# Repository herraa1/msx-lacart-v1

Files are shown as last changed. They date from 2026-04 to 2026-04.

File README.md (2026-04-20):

# MSX LOGICAL ANALYZER CART

This is a MSX cartridge to facilitate the use of a Logical Analyzer with MSX cartridges and slot signals.

It uses [Agustín Gimenez Bernad](https://github.com/gusmanb) Raspberry Pico 2 based [logicanalizer](https://github.com/gusmanb/logicanalyzer) as a companion card.

## Current Status

* First prototype PCB sent for manufacturing as of Apr 3rd 2026.
* First prototype PCB tested successfully as of Apr 18th 2026.

> [!NOTE]
> Documentation in progress

## [Hardware](hardware/kicad/)

The msx-lacart is made of a 4-layer PCB with minimal components.

### [msx-lacart-v1-build1](hardware/kicad/msx-lacart-v1-build1/)

:white_check_mark: This board has been successfully built and tested.

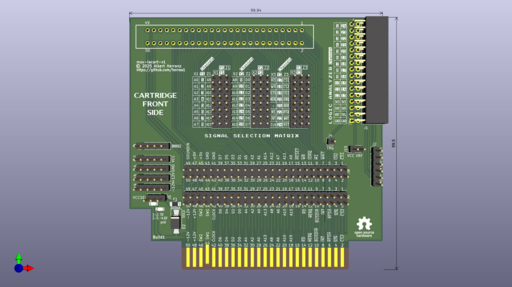
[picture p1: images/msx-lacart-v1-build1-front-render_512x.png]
[](images/msx-lacart-v1-build1-front-render.png)

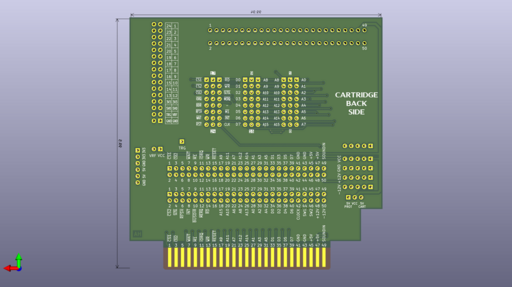
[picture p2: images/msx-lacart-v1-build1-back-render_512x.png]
[](images/msx-lacart-v1-build1-back-render.png)

[Bill Of Materials (BoM)](https://htmlpreview.github.io/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)

[Schematic and PCB](https://kicanvas.org/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)

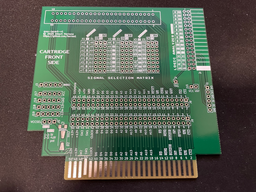
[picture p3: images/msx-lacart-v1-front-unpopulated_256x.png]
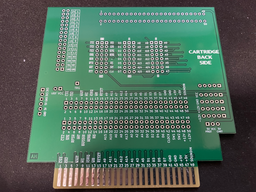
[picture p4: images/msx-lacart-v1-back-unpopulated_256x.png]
|[](images/msx-lacart-v1-front-unpopulated-9145.png)|[](images/msx-lacart-v1-back-unpopulated-9146.png)|
|-|-|
|msx-lacart-v1 build1<br>PCB unpopulated front|msx-lacart-v1 build1<br>PCB unpopulated back|

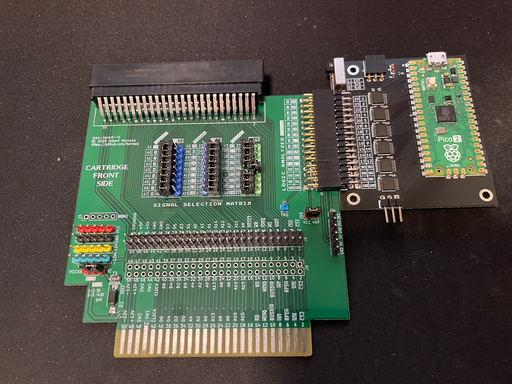
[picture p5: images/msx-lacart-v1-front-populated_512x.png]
|[](images/msx-lacart-v1-front-populated-9143.png)|
|:--|
|msx-lacart-v1 build1 PCB populated front|

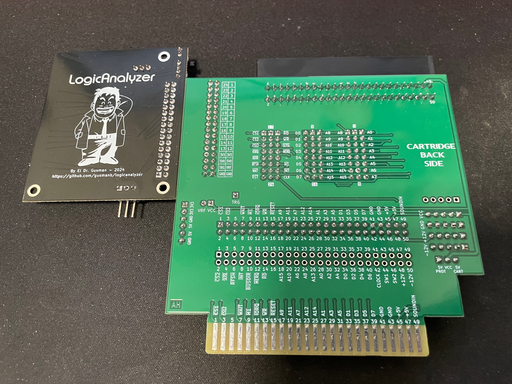
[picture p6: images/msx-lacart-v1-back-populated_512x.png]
|[](images/msx-lacart-v1-back-populated-9144.png)|
|:--|
|msx-lacart-v1 build1 PCB populated back|

## Usage

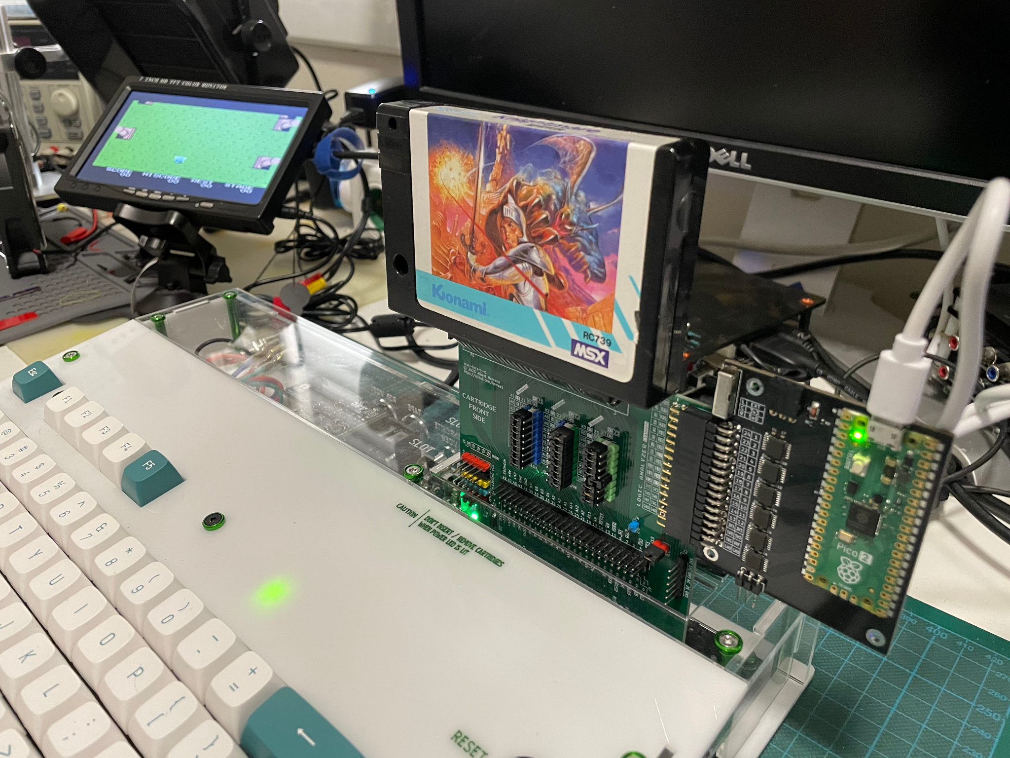
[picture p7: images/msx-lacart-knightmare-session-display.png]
|[](images/msx-lacart-knightmare-session-display.png)|
|:--|
|msx-lacart-v1 inserted into slot1 of a MSX JFF inspecting a Knighmare cartridge|

|[](images/msx-lacart-knightmare-session-analyzer.png)|
|:--|
|msx-lacart-v1 with Logic Analyzer capture session|

```
                    di                                      ;[0000] f3
                    jp        $02d7                         ;[0001] c3 d7 02
[...]
                    ld        a,$82                         ;[02d7] 3e 82
                    out       ($ab),a                       ;[02d9] d3 ab
                    xor       a                             ;[02db] af
                    out       ($a8),a                       ;[02dc] d3 a8
                    ld        a,$50                         ;[02de] 3e 50
                    out       ($aa),a                       ;[02e0] d3 aa
                    ld        de,$ffff                      ;[02e2] 11 ff ff
                    xor       a                             ;[02e5] af
                    ld        c,a                           ;[02e6] 4f
                    out       ($a8),a                       ;[02e7] d3 a8
                    sla       c                             ;[02e9] cb 21
                    ld        b,$00                         ;[02eb] 06 00
                    ld        hl,$ffff                      ;[02ed] 21 ff ff
                    ld        (hl),$f0                      ;[02f0] 36 f0
                    ld        a,(hl)                        ;[02f2] 7e
                    sub       $0f                           ;[02f3] d6 0f
                    jr        nz,$0302                      ;[02f5] 20 0b
[...]
                    ld        hl,$bf00                      ;[0302] 21 00 bf
                    ld        a,(hl)                        ;[0305] 7e
                    cpl                                     ;[0306] 2f
                    ld        (hl),a                        ;[0307] 77
```
||
|:--|
|Original MSX BIOS Z80 instructions from BIOS disassembly|

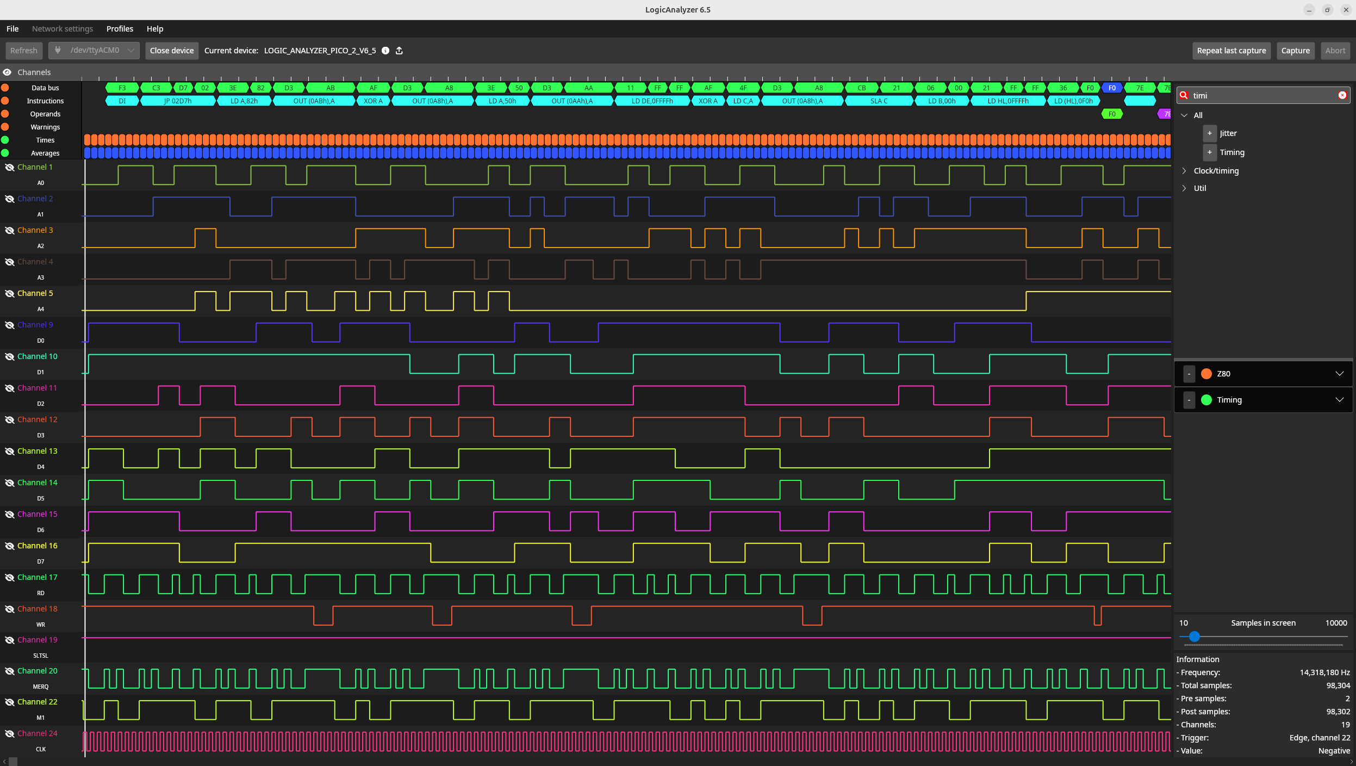
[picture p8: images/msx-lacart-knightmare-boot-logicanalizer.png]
|[](images/msx-lacart-knightmare-boot-logicanalizer.png)|
|:--|
|El Dr Gusman Logic Analyzer 6.5 showing MSX BIOS Z80 boot instructions captured using msx-lacart-v1|

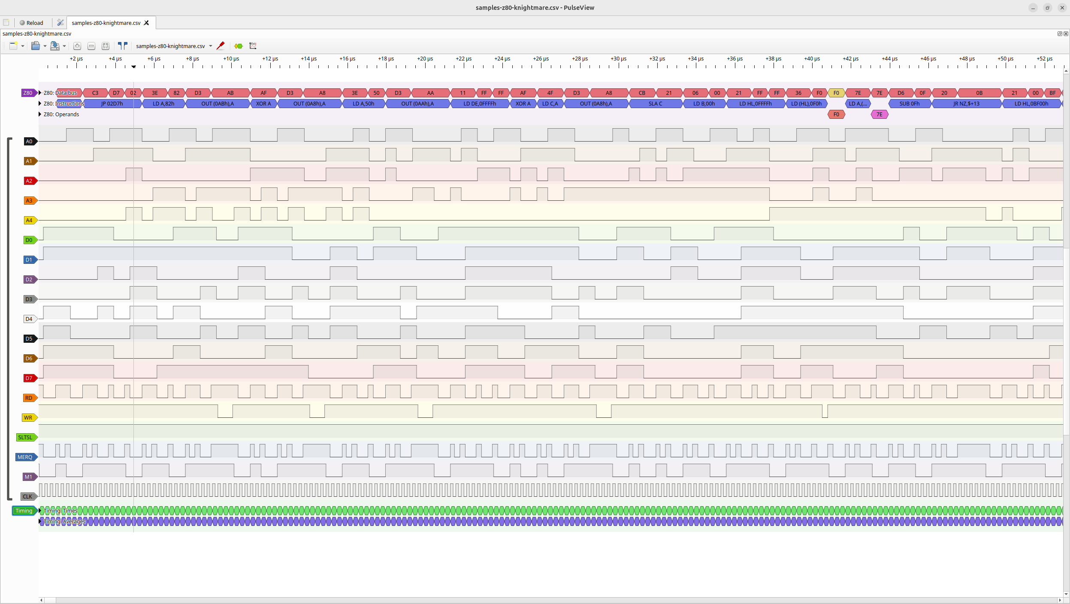
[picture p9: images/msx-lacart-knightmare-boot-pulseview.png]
|[](images/msx-lacart-knightmare-boot-pulseview.png)|
|:--|
|PulseView loaded with CSV export of MSX BIOS Z80 boot instructions captured using msx-lacart-v1|

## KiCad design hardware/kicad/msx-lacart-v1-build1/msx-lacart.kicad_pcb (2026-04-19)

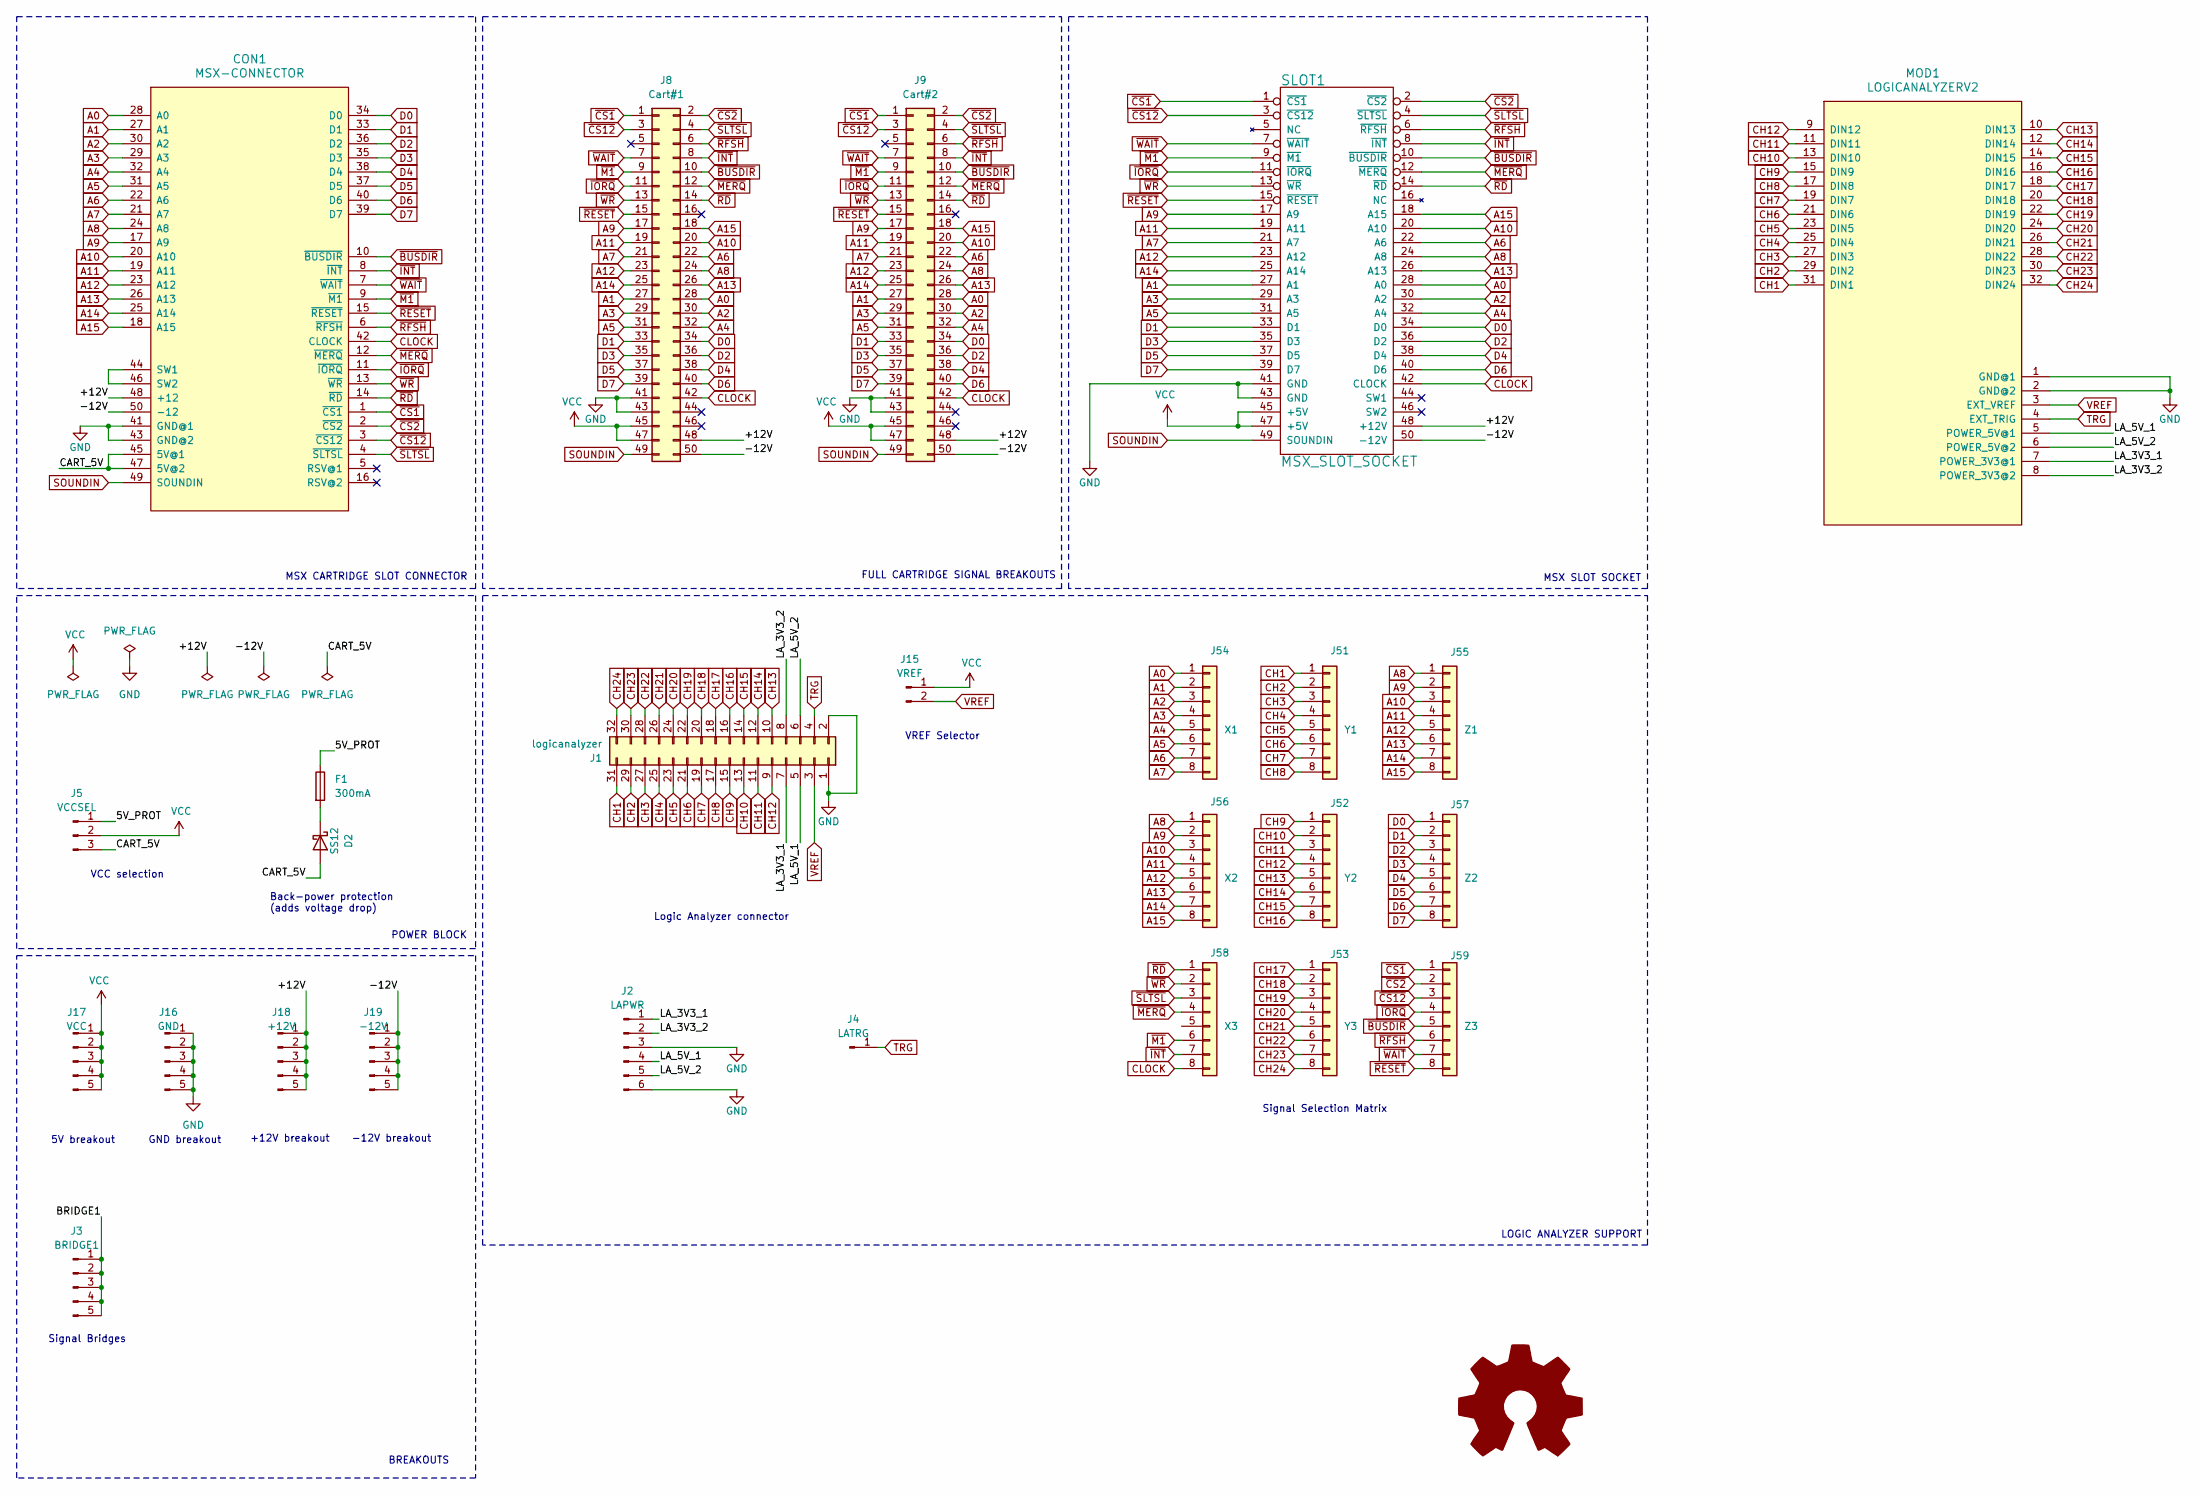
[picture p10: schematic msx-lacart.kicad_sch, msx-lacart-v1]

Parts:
CON1: MSX-CONNECTOR; CARTRIDGE_MSX_NOCUT
D2: SS12; D_SMA-SMB_Universal_Handsoldering
F1: 300mA; Fuse_1206_3216Metric_Pad1.42x1.75mm_HandSolder
J1: logicanalyzer; PinSocket_2x16_P2.54mm_Horizontal
J2: LAPWR; PinHeader_1x06_P2.54mm_Vertical
J3: BRIDGE1; PinHeader_1x05_P2.54mm_Vertical
J4: LATRG; PinHeader_1x01_P2.54mm_Vertical
J5: VCCSEL; PinHeader_1x03_P2.54mm_Vertical
J8: Cart#1; PinHeader_2x25_P2.54mm_Vertical
J9: Cart#2; PinHeader_2x25_P2.54mm_Vertical
J15: VREF; PinHeader_1x02_P2.54mm_Vertical
J16: GND; PinHeader_1x05_P2.54mm_Vertical
J17: VCC; PinHeader_1x05_P2.54mm_Vertical
J18: +12V; PinHeader_1x05_P2.54mm_Vertical
J19: -12V; PinHeader_1x05_P2.54mm_Vertical
J51: Y1; PinHeaderCustom_1x08_P2.54mm_Vertical
J52: Y2; PinHeaderCustom_1x08_P2.54mm_Vertical
J53: Y3; PinHeaderCustom_1x08_P2.54mm_Vertical
J54: X1; PinHeaderCustom_1x08_P2.54mm_Vertical
J55: Z1; PinHeaderCustom_1x08_P2.54mm_Vertical
J56: X2; PinHeaderCustom_1x08_P2.54mm_Vertical
J57: Z2; PinHeaderCustom_1x08_P2.54mm_Vertical
J58: X3; PinHeaderCustom_1x08_P2.54mm_Vertical
J59: Z3; PinHeaderCustom_1x08_P2.54mm_Vertical
MOD1: LOGICANALYZERV2; LogicAnalyzerV2
SLOT1: MSX_SLOT_SOCKET; Conn_Edge_50P
SYM1: Logo_Open_Hardware_Large; OSHW-Logo_7.5x8mm_SilkScreen

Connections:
/5V_PROT: F1.1, J5.1
/+12V: CON1.48 (+12), J8.48, J9.48, J18.1, J18.2, J18.3, J18.4, J18.5, SLOT1.48 (+12V)
/-12V: CON1.50 (-12), J8.50, J9.50, J19.1, J19.2, J19.3, J19.4, J19.5, SLOT1.50 (-12V)
/BRIDGE1: J3.1, J3.2, J3.3, J3.4, J3.5
/CART_5V: CON1.45 (5V@1), CON1.47 (5V@2), D2.2 (A), J5.3
/LA_3V3_1: J1.7, J2.1, MOD1.7 (POWER_3V3@1)
/LA_3V3_2: J1.8, J2.2, MOD1.8 (POWER_3V3@2)
/LA_5V_1: J1.5, J2.4, MOD1.5 (POWER_5V@1)
/LA_5V_2: J1.6, J2.5, MOD1.6 (POWER_5V@2)
A0: CON1.28 (A0), J8.28, J9.28, J54.1, SLOT1.28 (A0)
A1: CON1.27 (A1), J8.27, J9.27, J54.2, SLOT1.27 (A1)
A2: CON1.30 (A2), J8.30, J9.30, J54.3, SLOT1.30 (A2)
A3: CON1.29 (A3), J8.29, J9.29, J54.4, SLOT1.29 (A3)
A4: CON1.32 (A4), J8.32, J9.32, J54.5, SLOT1.32 (A4)
A5: CON1.31 (A5), J8.31, J9.31, J54.6, SLOT1.31 (A5)
A6: CON1.22 (A6), J8.22, J9.22, J54.7, SLOT1.22 (A6)
A7: CON1.21 (A7), J8.21, J9.21, J54.8, SLOT1.21 (A7)
A8: CON1.24 (A8), J8.24, J9.24, J55.1, J56.1, SLOT1.24 (A8)
A9: CON1.17 (A9), J8.17, J9.17, J55.2, J56.2, SLOT1.17 (A9)
A10: CON1.20 (A10), J8.20, J9.20, J55.3, J56.3, SLOT1.20 (A10)
A11: CON1.19 (A11), J8.19, J9.19, J55.4, J56.4, SLOT1.19 (A11)
A12: CON1.23 (A12), J8.23, J9.23, J55.5, J56.5, SLOT1.23 (A12)
A13: CON1.26 (A13), J8.26, J9.26, J55.6, J56.6, SLOT1.26 (A13)
A14: CON1.25 (A14), J8.25, J9.25, J55.7, J56.7, SLOT1.25 (A14)
A15: CON1.18 (A15), J8.18, J9.18, J55.8, J56.8, SLOT1.18 (A15)
CH1: J1.31, J51.1, MOD1.31 (DIN1)
CH2: J1.29, J51.2, MOD1.29 (DIN2)
CH3: J1.27, J51.3, MOD1.27 (DIN3)
CH4: J1.25, J51.4, MOD1.25 (DIN4)
CH5: J1.23, J51.5, MOD1.23 (DIN5)
CH6: J1.21, J51.6, MOD1.21 (DIN6)
CH7: J1.19, J51.7, MOD1.19 (DIN7)
CH8: J1.17, J51.8, MOD1.17 (DIN8)
CH9: J1.15, J52.1, MOD1.15 (DIN9)
CH10: J1.13, J52.2, MOD1.13 (DIN10)
CH11: J1.11, J52.3, MOD1.11 (DIN11)
CH12: J1.9, J52.4, MOD1.9 (DIN12)
CH13: J1.10, J52.5, MOD1.10 (DIN13)
CH14: J1.12, J52.6, MOD1.12 (DIN14)
CH15: J1.14, J52.7, MOD1.14 (DIN15)
CH16: J1.16, J52.8, MOD1.16 (DIN16)
CH17: J1.18, J53.1, MOD1.18 (DIN17)
CH18: J1.20, J53.2, MOD1.20 (DIN18)
CH19: J1.22, J53.3, MOD1.22 (DIN19)
CH20: J1.24, J53.4, MOD1.24 (DIN20)
CH21: J1.26, J53.5, MOD1.26 (DIN21)
CH22: J1.28, J53.6, MOD1.28 (DIN22)
CH23: J1.30, J53.7, MOD1.30 (DIN23)
CH24: J1.32, J53.8, MOD1.32 (DIN24)
CLOCK: CON1.42 (CLOCK), J8.42, J9.42, J58.8, SLOT1.42 (CLOCK)
D0: CON1.34 (D0), J8.34, J9.34, J57.1, SLOT1.34 (D0)
D1: CON1.33 (D1), J8.33, J9.33, J57.2, SLOT1.33 (D1)
D2: CON1.36 (D2), J8.36, J9.36, J57.3, SLOT1.36 (D2~)
D3: CON1.35 (D3), J8.35, J9.35, J57.4, SLOT1.35 (D3)
D4: CON1.38 (D4), J8.38, J9.38, J57.5, SLOT1.38 (D4)
D5: CON1.37 (D5), J8.37, J9.37, J57.6, SLOT1.37 (D5)
D6: CON1.40 (D6), J8.40, J9.40, J57.7, SLOT1.40 (D6)
D7: CON1.39 (D7), J8.39, J9.39, J57.8, SLOT1.39 (D7)
GND: CON1.41 (GND@1), CON1.43 (GND@2), J1.1, J1.2, J2.3, J2.6, J8.41, J8.43, J9.41, J9.43, J16.1, J16.2, J16.3, J16.4, J16.5, MOD1.1 (GND@1), MOD1.2 (GND@2), SLOT1.41 (GND), SLOT1.43 (GND)
unnamed: CON1.44 (SW1), CON1.46 (SW2)
unnamed: D2.1 (K), F1.2
SOUNDIN: CON1.49 (SOUNDIN), J8.49, J9.49, SLOT1.49 (SOUNDIN)
TRG: J1.4, J4.1, MOD1.4 (EXT_TRIG)
VCC: J5.2, J8.45, J8.47, J9.45, J9.47, J15.1, J17.1, J17.2, J17.3, J17.4, J17.5, SLOT1.45 (+5V), SLOT1.47 (+5V)
VREF: J1.3, J15.2, MOD1.3 (EXT_VREF)
~BUSDIR: CON1.10 (~BUSDIR), J8.10, J9.10, J59.5, SLOT1.10 (~BUSDIR)
~CS1: CON1.1 (~CS1), J8.1, J9.1, J59.1, SLOT1.1 (~CS1)
~CS2: CON1.2 (~CS2), J8.2, J9.2, J59.2, SLOT1.2 (~CS2)
~CS12: CON1.3 (~CS12), J8.3, J9.3, J59.3, SLOT1.3 (~CS12)
~INT: CON1.8 (~INT), J8.8, J9.8, J58.7, SLOT1.8 (~INT)
~IORQ: CON1.11 (~IORQ), J8.11, J9.11, J59.4, SLOT1.11 (~IORQ)
~M1: CON1.9 (~M1), J8.9, J9.9, J58.6, SLOT1.9 (~M1)
~MERQ: CON1.12 (~MERQ), J8.12, J9.12, J58.4, SLOT1.12 (~MERQ)
~RD: CON1.14 (~RD), J8.14, J9.14, J58.1, SLOT1.14 (~RD)
~RESET: CON1.15 (~RESET), J8.15, J9.15, J59.8, SLOT1.15 (~RESET)
~RFSH: CON1.6 (~RFSH), J8.6, J9.6, J59.6, SLOT1.6 (~RFSH)
~SLTSL: CON1.4 (~SLTSL), J8.4, J9.4, J58.3, SLOT1.4 (~SLTSL)
~WAIT: CON1.7 (~WAIT), J8.7, J9.7, J59.7, SLOT1.7 (~WAIT)
~WR: CON1.13 (~WR), J8.13, J9.13, J58.2, SLOT1.13 (~WR)

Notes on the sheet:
5V breakout
Back-power protection (adds voltage drop)
MSX SLOT SOCKET
-12V breakout
MSX CARTRIDGE SLOT CONNECTOR
Logic Analyzer connector
+12V breakout
Signal Selection Matrix
GND breakout
POWER BLOCK
LOGIC ANALYZER SUPPORT
FULL CARTRIDGE SIGNAL BREAKOUTS
Signal Bridges
BREAKOUTS
VREF Selector
VCC selection

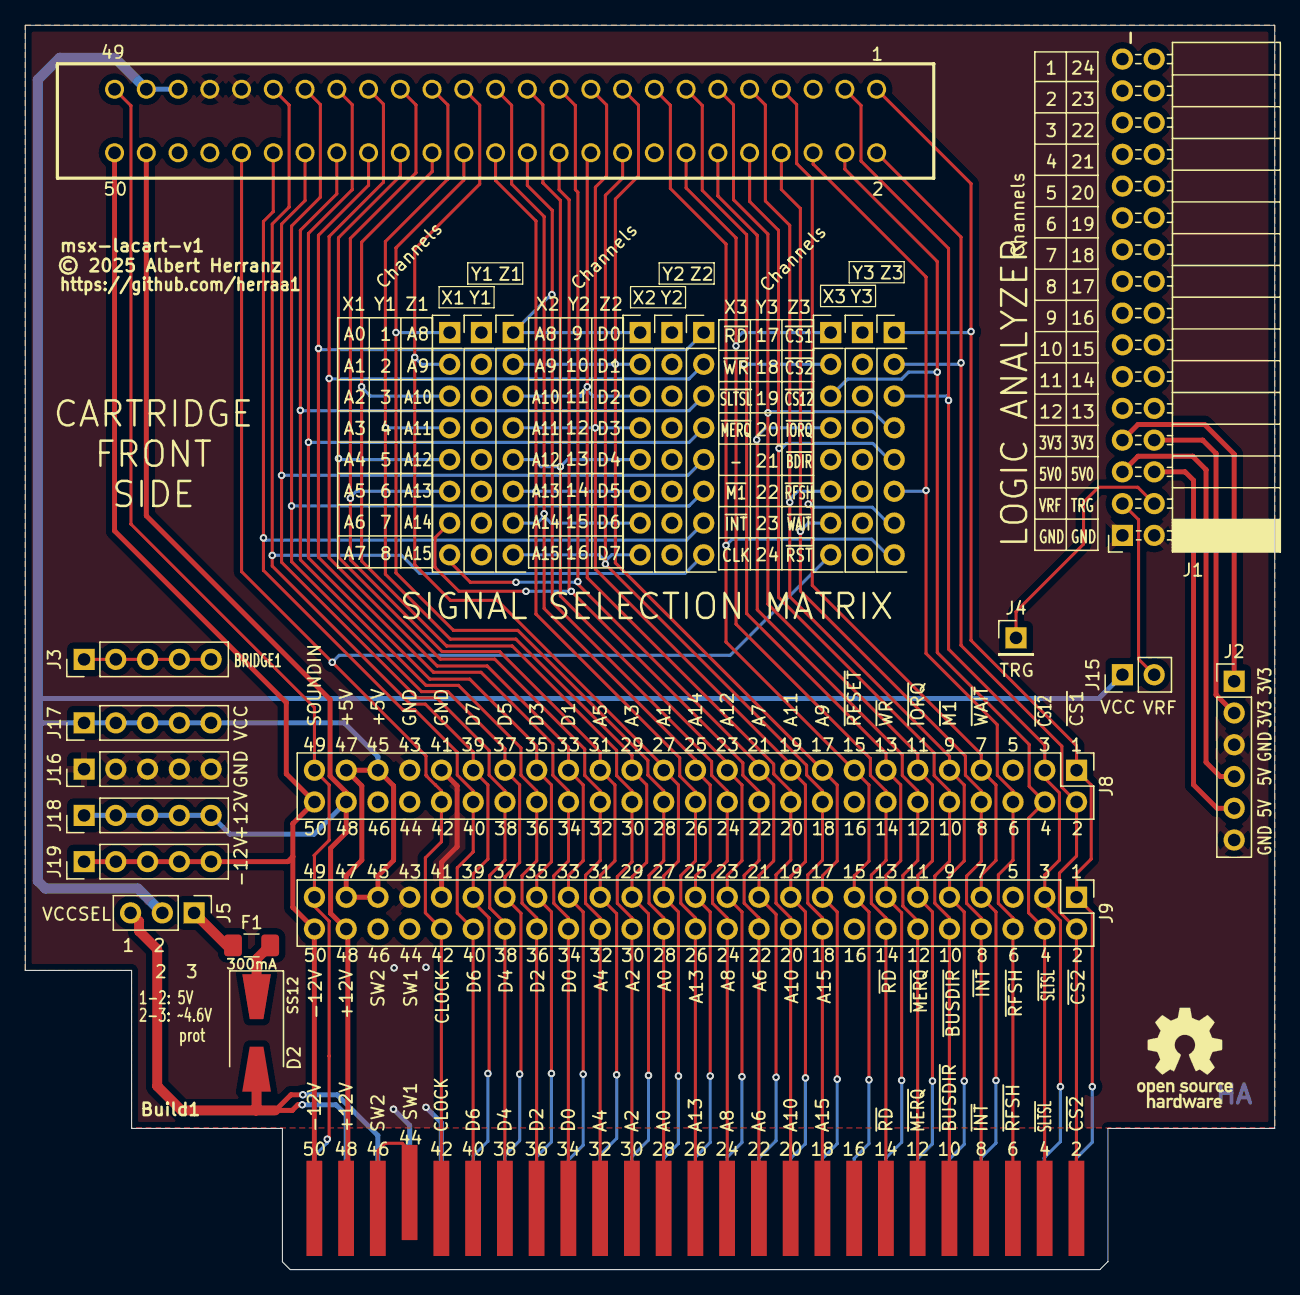
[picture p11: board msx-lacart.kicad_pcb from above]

Board: 4 copper layers, 99.9 x 99.5 mm, 26 parts (0 on the bottom side), 79 nets.

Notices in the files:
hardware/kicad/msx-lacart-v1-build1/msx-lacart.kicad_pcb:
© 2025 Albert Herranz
